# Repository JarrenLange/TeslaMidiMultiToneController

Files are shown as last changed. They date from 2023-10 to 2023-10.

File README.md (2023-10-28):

# DRSSTC Midi Multi Tone Controller
This project is the repository for a dual tone, dual Tesla coil midi controller. Includes Schematics, code and design files for the Housing used. Also includes a basic Midi Tester, to test Midi files and channels before turning on a Tesla Coil. 
FrontPanel

# Design 
This controller is designed to interface with Dual Resonant Solid State Tesla Coils (DRSSTC) that utilise Fibre optic activated control boards based upon the Steve Ward design (https://www.stevehv.4hv.org/new_driver.html). 
I have tested this design with two Tesla coils that utilise the LoneOceans UD2.7 Controller (https://www.loneoceans.com/labs/sales/ud27/). 
The controller has been successfully used during presentations in front of an audience on several occassions (e.g. https://www.uni-paderborn.de/en/news-item/127166)
This device connects to a computer via a USB-C cable and has an LCD display for the setup and parameterisation of the Tesla coil operation.
Using free software it received MIDI commands from the PC, and then activates the Tesla coils with variable ON durations (with a settable maximum) to play musical notes with variable volumes. 
Its designed to be Low-cost and built using standard components, such as the STM32F411 Blackpill development boards.
It is also designed to be as safe as possible, with two mechanical switches being available to break fibre optic operation.
The one switch is a momentary switch, which ensures that a user must hold onto the switch for continued operation.

# Safety Warning
Working and operating Telsa coils is dangerous.
The Fibre Optic systems should not be relied upon to ensure saftey of the Tesla coils. 
At all time a means of Turning off the Tesla coils should be present and tested.
While all efforts have been taken to design this Controller as well as possible, it cannot be guaranteed.
I personally test the controller thoroughly after new code is uploaded to ensure that the maximum on-time is obeyed.

# Features
This controller can:

- Operate two Tesla coils at once. 
- Provide each Tesla coil with Dual Tones.
- Has a settable maximum ON-Time per Tesla coil.
- Utiliseds interupt based controls ensuring minimal Jitter and error in Tesla coil on times.
- Utilises variable on times, to emulate variable tone volume. 
- Ensures an off time between on pulses, to allow the resonant system to discharge, for consistent performance.
- Has a fixed frequency mode. 
- Uses a USB-C cable for communication and power.

# Required Software
In order to operate this controller the following software is recommended.
- LoopMidi by Tobias Erichsen https://www.tobias-erichsen.de/software/loopmidi.html
- Hairless Midi https://github.com/projectgus/hairless-midiserial

LoopMidi creates a locallised Midi system through which midi signals can be rerouted.
Hairless Midi takes these midi Signals and sends it out a Serial port. 

The STM32F411 is then configured as a Virtual Serial Port to receive these commands. 

# Operational Description.

## Safety implementation
This controller assumes that the Tesla coil waits for an on pulse through the fibre optic connection and then only oscilates the Tesla coil while the fibre optic signal is present.
This means that the Tesla coil should remain in an "armed" state (so ready for oscillation) until the signal is present. 
Hence ensuring the Fibre optic transmitters remain completely unpowered, means that the Tesla coils should not fire.
This is an element of the safety functionality, with which two switchs need to be in the firing position before a signal from the microcontroller can be sent.
This minimises errors due to my own stupidity, (such as a software bug).

## On time and dwell time
The actual enable pulse of the microcontroller is driven directly by its timer peripherals, setup for a single pulse mode.
When triggered, the firing timer (timer with its IO connected to the Fibre optic enable), fires in Single Pulse mode. 
The duration of the ON pulse is determined by the required ON time, and the total timer duration is the sum of the ON time and the dwell time. 
During firing, the timer is blocked, such that it cant be refired, until the total pulse is finished. 

## Tone Generation and Music
In the current implementation, two more timers are used to generate the tones passed on to the firing timers. 
These timers are configured to run freely with the frequency determined either from the Fixed-Frequency settings, or the Midi Commands.
Upon a timer reset interupt, the timer will try to fire the asscociated Fibre optic channel, provided the timer is not already firing.
Simple as.

# Idemnification.
Every effort has been taken to ensure that this device and software operates as intended and as safe as possible.  
However I cannot account for variability in the components other people use for example.
I also cannot guarantee a lack of my own stupidity. 
Hence I do not accept any responsibility for any harm or damage that might occur directly or indirectly due to this device.
Reproduce this project at your own risk.
By copying/working on this repository you acknowledge that you take this risk on willingly.

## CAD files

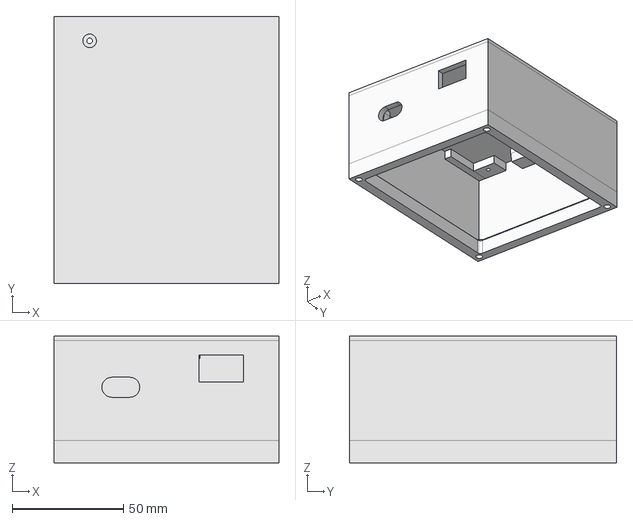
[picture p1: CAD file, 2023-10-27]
3DFiles/Housing.FCstd
101.0 x 120.0 x 57.0 mm

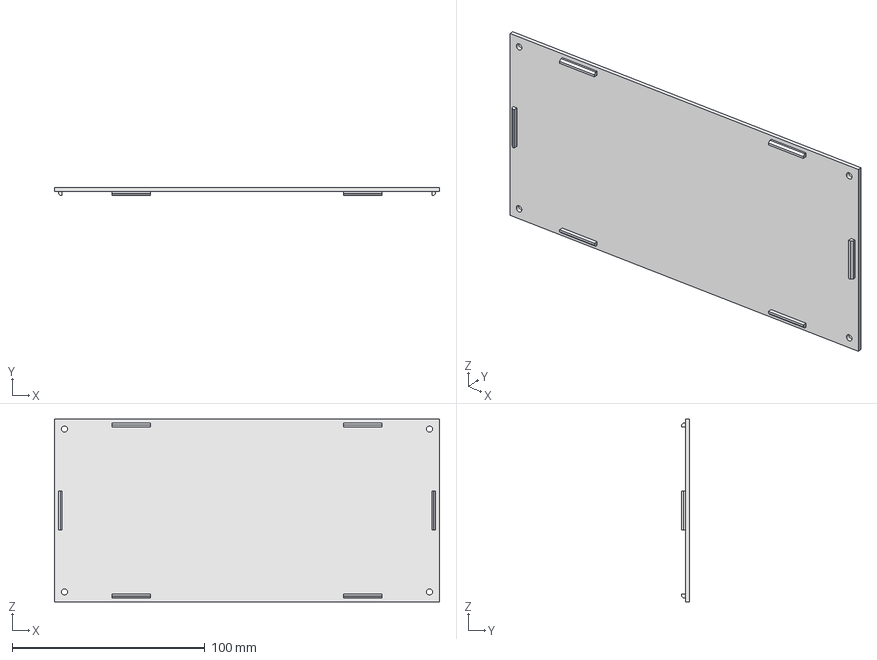
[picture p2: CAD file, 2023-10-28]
Tester/3DFiles/FibreTester.FCStd
200.0 x 4.00 x 95.0 mm

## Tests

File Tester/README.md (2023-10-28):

# DRSSTC Midi Control Tester
Testing a MIDI file, to make sure that it would sound decent on a set of Tesla coils is difficult.
Specifically when one downloads a Midi file off the internet and does not know if the certain channels work well in a limited frequency pulse pattern.
So I took apart an old set of computer speakers and reused the speakers to build a small tester.

FrontPanel

# Design 
The design uses a TSC426 Mosfet driver (that I easily had on hand) to buffer and invert the nominally HI signal from the Fibre optic receivers.
This means that the speakers should generate a single pulse of air pressure, similair to a Tesla arc for each pulse.
This helps to test the entire MIDI chain, before the Tesla coils are turned on.

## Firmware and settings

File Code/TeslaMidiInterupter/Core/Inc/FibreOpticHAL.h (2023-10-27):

/*
 * FibreOpticHAL.h
 *
 *  Created on: Sep 24, 2023
 *      Author: Jarren Lange
 */

#ifndef INC_FIBREOPTICHAL_H_
#define INC_FIBREOPTICHAL_H_
#include "stm32f4xx_hal.h"

//Hardware handles
extern TIM_HandleTypeDef htim2;
extern TIM_HandleTypeDef htim3;
extern TIM_HandleTypeDef htim4;
extern TIM_HandleTypeDef htim5;
extern TIM_HandleTypeDef htim10;
extern TIM_HandleTypeDef htim11;


//Gains used to define Hardware to external characteristics
#define TIM3_BASE_DELAY_OFFSET		5
#define TIM3_delayuSGain	48
#define TIM2_freqHzGain 	96000000
#define TIM10_freqHzGain 	96000000/(15+1) //(Clk/Prescale+1)


//Second Tesla Hardware characteristics
#define TIM5_freqHzGain 	96000000
#define TIM4_delayuSGain	48
#define TIM11_freqHzGain 	96000000/(15+1) //(Clk/Prescale+1)
#define TIM_16bit_MIN_FREQ 	96000000/(16384*(15+1)) //(Clk/Prescale+1)

#define CH_FREE	0
#define CH_FIRE	1
#define CH_DWELL 2

#define EN_DWELL
#define DEFAULT_DWELL	200

#define MIDI_FREQ_TIMEOUT	1000

#define MAX_TIM3_PERIOD_US	(65535/(48*(1+1)))
#define MAX_TIM4_PERIOD_US	(65535/(48*(1+1)))

#define MAX_VELOCITY	127.0
#define DEFAULT_VELOCITY	126

//

void fireCHA(uint8_t);
void fireCHB(uint8_t);

//Individual functions for the first Telsa Channel
void setCHAFreq1(float);
void setCHAFreq2(float);
void setCHAFreq1wVelocity(uint16_t, uint8_t);
void setCHAFreq2wVelocity(uint16_t, uint8_t);
void setCHADwellPeriod(float);
void setCHASoloEnable(uint8_t);
void setCHAActivePeriod(float);


//Individual functions for the second Telsa Channel
void setCHBFreq1(float);
void setCHBFreq2(float);
void setCHBFreq1wVelocity(uint16_t, uint8_t);
void setCHBFreq2wVelocity(uint16_t, uint8_t);
void setCHBDwellPeriod(float);
void setCHBSoloEnable(uint8_t);
void setCHBActivePeriod(float);

void defineFiringActiveFBPins(GPIO_TypeDef* PortCHA, uint16_t pinCHA,GPIO_TypeDef* PortCHB, uint16_t pinCHB );
void defineSoloEnablePins(GPIO_TypeDef* PortCHA, uint16_t pinCHA,GPIO_TypeDef* PortCHB, uint16_t pinCHB );
uint8_t isFiringActiveCHA();
uint8_t isFiringActiveCHB();

void fireTIM3(uint8_t);
void fireTIM4(uint8_t);

#endif /* INC_FIBREOPTICHAL_H_ */

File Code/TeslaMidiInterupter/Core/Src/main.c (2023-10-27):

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
/* Includes ------------------------------------------------------------------*/
#include "main.h"
#include "usb_device.h"

TIM_HandleTypeDef htim1;
TIM_HandleTypeDef htim2;
TIM_HandleTypeDef htim3;
TIM_HandleTypeDef htim4;
TIM_HandleTypeDef htim5;
TIM_HandleTypeDef htim9;
TIM_HandleTypeDef htim10;
TIM_HandleTypeDef htim11;

/* USER CODE BEGIN PV */

uint8_t encoderPrev;
uint8_t encPos;
int8_t encDir;


uint64_t lastEncTime;
uint64_t lastButTime;
uint64_t lastDoubleTime;
uint64_t lastDispTime;
uint64_t lastDispResTime;

//Timeouts for the MIDI processes, to timeout a MIDI tone
//Because sometimes the Micro misses a MIDI command to turn off

extern uint64_t lastCHA1Time;
extern uint64_t lastCHA2Time;
extern uint64_t lastCHB1Time;
extern uint64_t lastCHB2Time;
extern uint8_t dwell_block_CHA;
extern uint8_t dwell_block_CHB;

struct Lcd_HandleTypeDef lcd;
/* USER CODE END PV */

void SystemClock_Config(void);
static void MX_GPIO_Init(void);
static void MX_TIM2_Init(void);
static void MX_TIM3_Init(void);
static void MX_TIM4_Init(void);
static void MX_TIM5_Init(void);
static void MX_TIM9_Init(void);
static void MX_TIM10_Init(void);
static void MX_TIM11_Init(void);
static void MX_TIM1_Init(void);
/**
  * @brief  The application entry point.
  * @retval int
  */
int main(void)
{
  /* MCU Configuration--------------------------------------------------------*/

  /* Reset of all peripherals, Initializes the Flash interface and the Systick. */
  HAL_Init();

  /* Configure the system clock */
  SystemClock_Config();

  /* Initialize all configured peripherals */
  MX_GPIO_Init();
  MX_USB_DEVICE_Init();
  MX_TIM2_Init();
  MX_TIM3_Init();
  MX_TIM4_Init();
  MX_TIM5_Init();
  MX_TIM9_Init();
  MX_TIM10_Init();
  MX_TIM11_Init();
  MX_TIM1_Init();
  /* USER CODE BEGIN 2 */

  HAL_TIM_Base_Start_IT(&htim1);
  HAL_TIM_Base_Start_IT(&htim2);
  HAL_TIM_Base_Start_IT(&htim3);
  HAL_TIM_Base_Start_IT(&htim4);
  HAL_TIM_Base_Start_IT(&htim5);
  //HAL_TIM_Base_Start_IT(&htim9);
  HAL_TIM_Base_Start_IT(&htim10);
  //HAL_TIM_Base_Start_IT(&htim11);

  HAL_TIM_PWM_Start_IT(&htim1, TIM_CHANNEL_1);

  Lcd_PortType ports[] = {
		  LCD_D0_GPIO_Port, LCD_D1_GPIO_Port, LCD_D2_GPIO_Port, LCD_D3_GPIO_Port
  };

  Lcd_PinType pins[] = {LCD_D0_Pin, LCD_D1_Pin, LCD_D2_Pin, LCD_D3_Pin};


  lcd = Lcd_create(ports, pins, LCD_RS_GPIO_Port, LCD_RS_Pin, LCD_E_GPIO_Port, LCD_E_Pin, LCD_4_BIT_MODE);

  Lcd_cursor(&lcd, 0,0);
  Lcd_string(&lcd, "Tesla FibreOptic");
  Lcd_cursor(&lcd, 1,0);
  Lcd_string(&lcd, "Dual Tesla Control");
  Lcd_cursor(&lcd, 0,16);
  Lcd_string(&lcd, "V1.1");
  Lcd_cursor(&lcd, 1,16);
  Lcd_string(&lcd, "Dr. Jarren Lange");
  DELAY(1000);

  Lcd_cursor(&lcd, 1,2);

	initMenu();
	updateHardware();

	defineFiringActiveFBPins(FO_OUTPUT_EN_FB1_GPIO_Port, FO_OUTPUT_EN_FB1_Pin, FO_OUTPUT_EN_FB2_GPIO_Port,FO_OUTPUT_EN_FB2_Pin);
	defineSoloEnablePins(SOLO_EN_CH1_GPIO_Port, SOLO_EN_CH1_Pin, SOLO_EN_CH2_GPIO_Port, SOLO_EN_CH2_Pin);

	initMIDI();
	registerMidiChannels(&FO_CHA_Params.midiCh1,&FO_CHA_Params.midiCh2,&FO_CHB_Params.midiCh1,&FO_CHB_Params.midiCh2);
	registerMIDIEnable(&currentMenuNO);//Since Fixed menu i zero, we can use this as a hack for the enable
  /* USER CODE END 2 */

  /* Infinite loop */
  /* USER CODE BEGIN WHILE */
  printf("Started\n");
  while (1)
  {
	  //Update the display every 200ms.
	  if((lastDispTime+200)<tim1_count)
	  {
		  updateDisplay();
		  lastDispTime =tim1_count;
	  }
	  //Reset the display every 4000ms.
	  //This is to counteract the occasional misoperation of the LCD, assumedly due to EMI (no idea on the source)
	  if((lastDispResTime+4000)<tim1_count)
	  {
		  lcd = Lcd_create(ports, pins, LCD_RS_GPIO_Port, LCD_RS_Pin, LCD_E_GPIO_Port, LCD_E_Pin, LCD_4_BIT_MODE);
		  lastDispResTime =tim1_count;
		  updateHardware();
	  }
	  //Check the timeouts if we are operating in MIDI mode.
	  if(currentMenuNO!=FIXED_F_MENU_NO)
	  {
		  //When in midi, it can happen that a tone kill signal is missed.
		  //For that reason we check the timeouts to stop a tone after a fixed time period.

		  checkChannelTimeouts();
	  }
    /* USER CODE END WHILE */

    /* USER CODE BEGIN 3 */
  }
  /* USER CODE END 3 */
}

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
/* USER CODE BEGIN 4 */
int _write(int file, char *ptr, int len) {
    CDC_Transmit_FS((uint8_t*) ptr, len);
    return len;
}


//Sometimes you need to forcefully shut down a frequency channel if it hasnt been updated in a while
void checkChannelTimeouts(){


	  if((lastCHA1Time+MIDI_FREQ_TIMEOUT)<tim1_count)
	  {
		  setCHAFreq1(0);
	  }
	  if((lastCHA2Time+MIDI_FREQ_TIMEOUT)<tim1_count)
	  {
		  setCHAFreq2(0);
	  }
	  if((lastCHB1Time+MIDI_FREQ_TIMEOUT)<tim1_count)
	  {
		  setCHBFreq1(0);
	  }
	  if((lastCHB2Time+MIDI_FREQ_TIMEOUT)<tim1_count)
	  {
		  setCHBFreq2(0);
	  }
}

void interuptCHA()
{
	HAL_GPIO_WritePin(CH1_Port, CH1_Pin, 0);
	HAL_TIM_PWM_Stop_IT(&htim3, TIM_CHANNEL_1);
	dwell_block_CHA=CH_FREE;//Allow a firing

}
void interuptCHB()
{
	//HAL_GPIO_WritePin(CH1_Port, CH1_Pin, 0);
	HAL_TIM_PWM_Stop_IT(&htim4, TIM_CHANNEL_3);
	dwell_block_CHB=CH_FREE;//Allow a firing

}
// Callback: timer has rolled over
void HAL_TIM_PeriodElapsedCallback(TIM_HandleTypeDef *htim)
{
	 // Check which  timer triggered this callback
	  if (htim == &htim3 )//TIM3 fires fibre optic 1
	  {
		  HAL_TIM_PWM_Stop_IT(&htim3, TIM_CHANNEL_1);
		  interuptCHA();
	  }
	  if (htim == &htim4 )//TIM4 fires fibre optic 2
	  {
		  HAL_TIM_PWM_Stop_IT(&htim4, TIM_CHANNEL_3);
		  interuptCHB();
	  }
	if (htim == &htim1 )//TIM1 is for the timeouts
		  {
		   tim1_count++;
		  }
	  if (htim == &htim2 )
	  {
		fireCHA(1);
	  }
	  if (htim == &htim5 )
	  {
		  fireCHB(1);
	  }
	  if (htim == &htim10 )
	  {
		  fireCHA(2);
	  }
	  if (htim == &htim11 )
	  {
		  fireCHB(2);
	  }
}
void HAL_GPIO_EXTI_Callback(uint16_t p)
{
	//For check if the interupt were caused by the rotatary encoder.
	if(p== ENC_A_Pin||p==ENC_B_Pin)
	{
		uint8_t temp = ((HAL_GPIO_ReadPin(ENC_A_GPIO_Port,ENC_A_Pin)<<1)&0x2)  | (HAL_GPIO_ReadPin(ENC_B_GPIO_Port,ENC_B_Pin)) ;
		uint8_t diff = (temp^encoderPrev);
		if(temp==0x02||temp==0x01){
			//part turn
			//Define the directions here.
			if((diff&0x2)==0x2){
				encDir=-1;
			}else{
				encDir=1;
			}
		}else{
			//Trying to detect actual changes in encoder position.
			//In our case a full rotation, which would cause 2 interupts in a short period of time
			if((lastEncTime+100)<tim1_count)
			{
				menuEncoderRotate(encDir);
				updateHardware();
				encPos += encDir;
				lastEncTime=tim1_count;
			}
		}


		encoderPrev= temp;
	}
	//Interupt source is the Encoder button.
	if(p==ENC_BUT_Pin)
	{
		//for the riding edge
		if( HAL_GPIO_ReadPin(ENC_BUT_GPIO_Port,ENC_BUT_Pin)==1)
		{
			//If the last button press happened between 100 ms since the last button press
			if((lastButTime+100)<tim1_count&&(lastDoubleTime+500)<tim1_count)//SinglePress
			{
				menuButPush();
			}
			//If the last button press was less than 500ms ago
		}else if((lastButTime+500)>tim1_count) {
				menuButDoublePush();
				lastDoubleTime = tim1_count;
		}

		lastButTime = tim1_count;
	}
}
void shutdownFixedFreq(){
	//When we switch to MIDI we kill all fixed frequency commands.
	setCHAFreq1(0);
	setCHAFreq2(0);
	setCHBFreq1(0);
	setCHBFreq2(0);
}
void updateDisplay()
{
	Lcd_cursor(&lcd, 0,0);
	Lcd_string(&lcd, currentMenuText());
	Lcd_cursor(&lcd, 1,0);
	Lcd_string(&lcd, currentSubMenuText());
	Lcd_cursor(&lcd, 1,13);
	Lcd_int(&lcd, currentMenuParameter());

	//Indicators of Firing
	Lcd_cursor(&lcd, 0,14);
	if(isFiringActiveCHA()){//Zero is active
		Lcd_string(&lcd, "*");
	}else{
		//display an S if solo is enabled
		if(FO_CHA_Params.enSolo)
		{
			Lcd_string(&lcd, "S");
		}else{
			Lcd_string(&lcd, "O");
		}
	}
	if(isFiringActiveCHB()){//Zero is active
		Lcd_string(&lcd, "*");
	}else{		//display an S if solo is enabled
		if(FO_CHB_Params.enSolo)
		{
			Lcd_string(&lcd, "S");
		}else{
			Lcd_string(&lcd, "O");
		}
	}

	updateDisplayFeedback();
	//Position of the cursor to indicate what is being edited.
	//Menu is indicated by the first character, parameter by the last.
	if(subMenuEditParam==1){
		Lcd_cursor(&lcd, 1,15);
	}else{
		Lcd_cursor(&lcd, 1,0);
	}

}

void updateDisplayFeedback()
{
	if(currentMenuNO == 0){
		//Start of the 3rd Line
		Lcd_cursor(&lcd, 0,16);
		Lcd_string(&lcd, "A");
		Lcd_int(&lcd, FO_CHA_Params.FixedFrequency_1);
		Lcd_string(&lcd, "*");
		Lcd_int(&lcd, FO_CHA_Params.FixedFrequency_2);
		Lcd_string(&lcd, "*");
		Lcd_int(&lcd, FO_CHA_Params.onTime);
		Lcd_string(&lcd, "*");
		Lcd_int(&lcd, FO_CHA_Params.dwellTime);
		//Start of the 4rd Line
		Lcd_cursor(&lcd, 1,16);
		Lcd_string(&lcd, "B");
		Lcd_int(&lcd, FO_CHB_Params.FixedFrequency_1);
		Lcd_string(&lcd, "*");
		Lcd_int(&lcd, FO_CHB_Params.FixedFrequency_2);
		Lcd_string(&lcd, "*");
		Lcd_int(&lcd, FO_CHB_Params.onTime);
		Lcd_string(&lcd, "*");
		Lcd_int(&lcd, FO_CHB_Params.dwellTime);
	}else{
		//Start of the 3rd Line
		Lcd_cursor(&lcd, 0,16);
		Lcd_string(&lcd, "A");
		Lcd_int(&lcd, FO_CHA_Params.midiCh1);
		Lcd_string(&lcd, "*");
		Lcd_int(&lcd, FO_CHA_Params.midiCh2);
		Lcd_string(&lcd, "*");
		Lcd_int(&lcd, FO_CHA_Params.onTime);
		Lcd_string(&lcd, "*");
		Lcd_int(&lcd, FO_CHA_Params.dwellTime);
		//Start of the 4rd Line
		Lcd_cursor(&lcd, 1,16);
		Lcd_string(&lcd, "B");
		Lcd_int(&lcd, FO_CHB_Params.midiCh1);
		Lcd_string(&lcd, "*");
		Lcd_int(&lcd, FO_CHB_Params.midiCh2);
		Lcd_string(&lcd, "*");
		Lcd_int(&lcd, FO_CHB_Params.onTime);
		Lcd_string(&lcd, "*");
		Lcd_int(&lcd, FO_CHB_Params.dwellTime);
	}

}
void updateHardware(){
	if(currentMenuNO == FIXED_F_MENU_NO)
	{
		//These Params come from the menu.'
		setCHAFreq1(FO_CHA_Params.FixedFrequency_1);
		setCHAFreq2(FO_CHA_Params.FixedFrequency_2);
		setCHAActivePeriod(FO_CHA_Params.onTime);
		setCHADwellPeriod(FO_CHA_Params.dwellTime);
		setCHASoloEnable(FO_CHA_Params.enSolo);
		//These Params come from the menu.'
		setCHBFreq1(FO_CHB_Params.FixedFrequency_1);
		setCHBFreq2(FO_CHB_Params.FixedFrequency_2);
		setCHBActivePeriod(FO_CHB_Params.onTime);
		//setCHBActivePeriod(40);
		setCHBDwellPeriod(FO_CHB_Params.dwellTime);
		setCHBSoloEnable(FO_CHB_Params.enSolo);
	}else
	{
		//These Params come from the menu.
		setCHAActivePeriod(FO_CHA_Params.onTime);
		setCHADwellPeriod(FO_CHA_Params.dwellTime);
		setCHASoloEnable(FO_CHA_Params.enSolo);

		setCHBActivePeriod(FO_CHB_Params.onTime);
		setCHBDwellPeriod(FO_CHB_Params.dwellTime);
		setCHBSoloEnable(FO_CHB_Params.enSolo);
	}

}
/* USER CODE END 4 */
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


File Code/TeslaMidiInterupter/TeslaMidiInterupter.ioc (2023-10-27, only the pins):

Mcu.UserName=STM32F411CEUx
PA11.Signal=USB_OTG_FS_DM
PA12.Signal=USB_OTG_FS_DP
PA2.GPIO_Label=LCD_D3
PA2.Signal=GPIO_Output
PA3.GPIO_Label=LCD_D2
PA3.Signal=GPIO_Output
PA4.GPIO_Label=LCD_D1
PA4.Signal=GPIO_Output
PA5.GPIO_Label=LCD_D0
PA5.Signal=GPIO_Output
PA6.GPIO_Label=LCD_E
PA6.Signal=GPIO_Output
PA7.GPIO_Label=LCD_RS
PA7.Signal=GPIO_Output
PA8.GPIO_Label=LCD_Backlight_PWM
PA8.Signal=S_TIM1_CH1
PB0.GPIO_Label=FO_OUTPUT_EN_FB1
PB0.Signal=GPIO_Input
PB1.GPIO_Label=FO_OUTPUT_EN_FB2
PB1.Signal=GPIO_Input
PB15.GPIO_Label=SOLO_EN_CH2
PB15.Signal=GPIO_Output
PB2.GPIO_Label=SOLO_EN_CH1
PB2.Signal=GPIO_Output
PB4.GPIO_Label=FO_OUTPUT_CH1
PB4.Signal=S_TIM3_CH1
PB6.GPIO_Label=ENC_A
PB6.Signal=GPXTI6
PB7.GPIO_Label=ENC_B
PB7.Signal=GPXTI7
PB8.GPIO_Label=FO_OUTPUT_CH2
PB8.Signal=S_TIM4_CH3
PB9.GPIO_Label=ENC_BUT
PB9.Signal=GPXTI9
PC13-ANTI_TAMP.GPIO_Label=BuiltInLED
PC13-ANTI_TAMP.Signal=GPIO_Output
PC14-OSC32_IN.Signal=GPIO_Output
PC15-OSC32_OUT.Signal=GPIO_Output

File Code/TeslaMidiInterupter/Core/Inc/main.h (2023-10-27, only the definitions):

#define BuiltInLED_Pin GPIO_PIN_13
#define BuiltInLED_GPIO_Port GPIOC
#define LCD_D3_Pin GPIO_PIN_2
#define LCD_D3_GPIO_Port GPIOA
#define LCD_D2_Pin GPIO_PIN_3
#define LCD_D2_GPIO_Port GPIOA
#define LCD_D1_Pin GPIO_PIN_4
#define LCD_D1_GPIO_Port GPIOA
#define LCD_D0_Pin GPIO_PIN_5
#define LCD_D0_GPIO_Port GPIOA
#define LCD_E_Pin GPIO_PIN_6
#define LCD_E_GPIO_Port GPIOA
#define LCD_RS_Pin GPIO_PIN_7
#define LCD_RS_GPIO_Port GPIOA
#define FO_OUTPUT_EN_FB1_Pin GPIO_PIN_0
#define FO_OUTPUT_EN_FB1_GPIO_Port GPIOB
#define FO_OUTPUT_EN_FB2_Pin GPIO_PIN_1
#define FO_OUTPUT_EN_FB2_GPIO_Port GPIOB
#define SOLO_EN_CH1_Pin GPIO_PIN_2
#define SOLO_EN_CH1_GPIO_Port GPIOB
#define SOLO_EN_CH2_Pin GPIO_PIN_15
#define SOLO_EN_CH2_GPIO_Port GPIOB
#define LCD_Backlight_PWM_Pin GPIO_PIN_8
#define LCD_Backlight_PWM_GPIO_Port GPIOA
#define FO_OUTPUT_CH1_Pin GPIO_PIN_4
#define FO_OUTPUT_CH1_GPIO_Port GPIOB
#define ENC_A_Pin GPIO_PIN_6
#define ENC_A_GPIO_Port GPIOB
#define ENC_A_EXTI_IRQn EXTI9_5_IRQn
#define ENC_B_Pin GPIO_PIN_7
#define ENC_B_GPIO_Port GPIOB
#define ENC_B_EXTI_IRQn EXTI9_5_IRQn
#define FO_OUTPUT_CH2_Pin GPIO_PIN_8
#define FO_OUTPUT_CH2_GPIO_Port GPIOB
#define ENC_BUT_Pin GPIO_PIN_9
#define ENC_BUT_GPIO_Port GPIOB
#define ENC_BUT_EXTI_IRQn EXTI9_5_IRQn
#define CH1_Pin GPIO_PIN_0
#define CH1_Port GPIOB

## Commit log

2023-10-27 InitialCommit
    Basic Initial commit, probably full of errors, but a first step to publishing this project.
    [FibreOpticInterface.kicad_sch, Housing.FCstd, LCDInterface.kicad_sch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]
2023-10-28 Added MIDI Tester
    [FibreTester.FCStd, Tester.kicad_pcb, Tester.kicad_sch]

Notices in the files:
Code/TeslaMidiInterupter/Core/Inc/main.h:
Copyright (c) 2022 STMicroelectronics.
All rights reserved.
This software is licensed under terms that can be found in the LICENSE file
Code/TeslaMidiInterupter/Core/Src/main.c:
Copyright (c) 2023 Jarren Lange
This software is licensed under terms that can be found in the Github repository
